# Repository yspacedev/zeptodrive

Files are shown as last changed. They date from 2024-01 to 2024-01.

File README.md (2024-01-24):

Constant current buck-boost converter based on the TPS63070 and INA180. The TPS63070 is a constant voltage buck-boost converter, so I'm using an INA180 (similar to this app note: https://www.ti.com/lit/an/slva419d/slva419d.pdf?ts=1689743420901) to convert it to a constant current converter.








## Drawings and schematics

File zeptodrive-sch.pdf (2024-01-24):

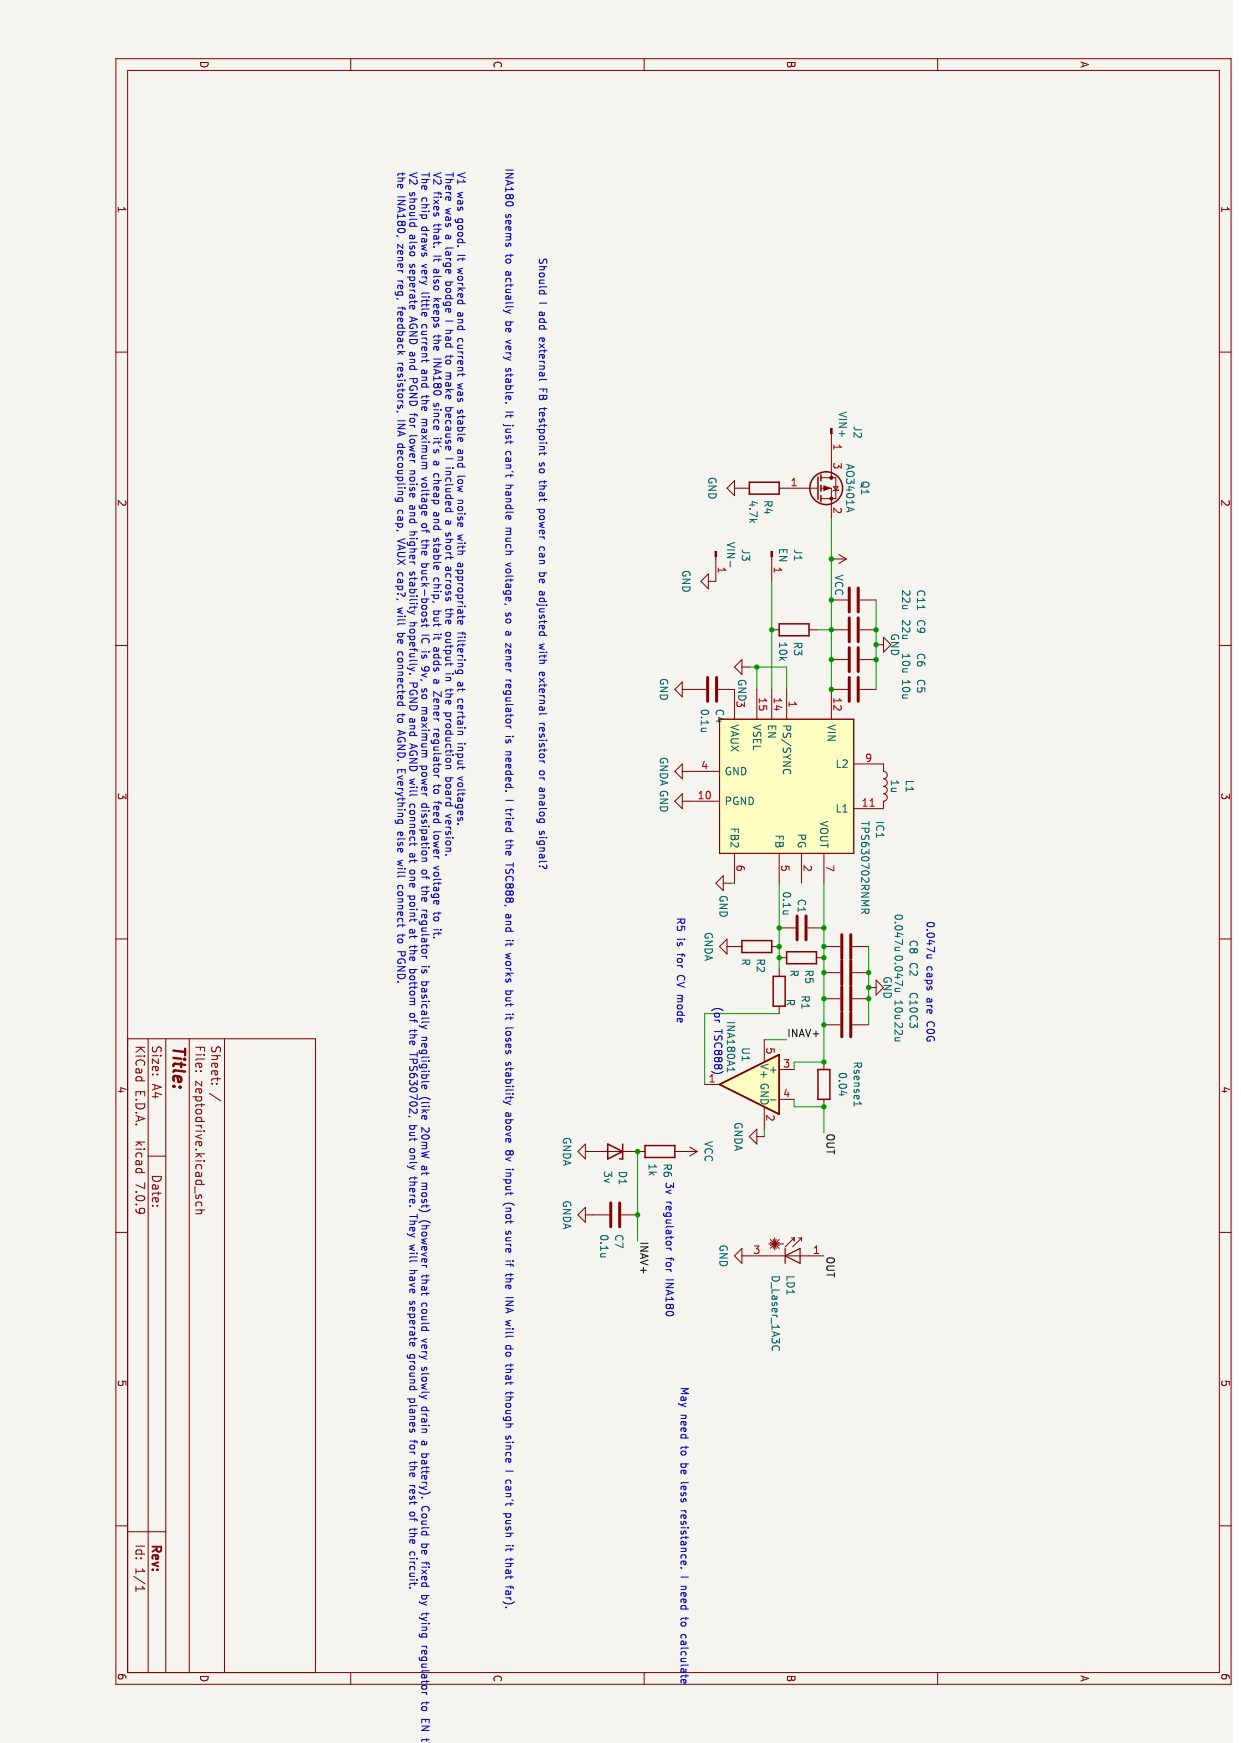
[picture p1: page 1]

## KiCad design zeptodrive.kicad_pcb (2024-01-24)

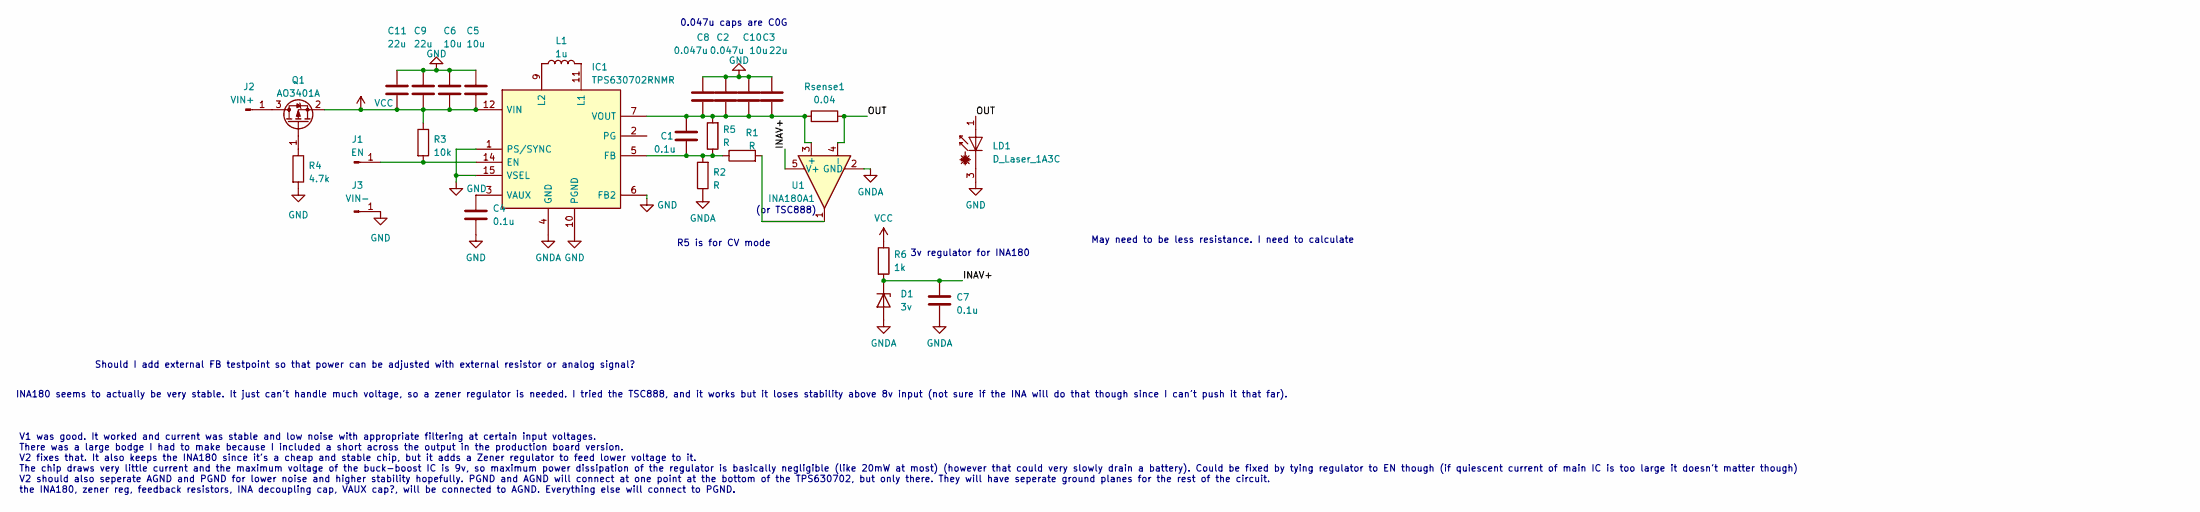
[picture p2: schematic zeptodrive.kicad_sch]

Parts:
C1, C4: 0.1u; C_0603_1608Metric
C2, C8: 0.047u; C_0805_2012Metric
C3, C9, C11: 22u; C_0805_2012Metric
C5, C6, C10: 10u; C_0805_2012Metric
C7: 0.1u; C_0402_1005Metric
D1: 3v; D_SOD-523
IC1: TPS630702RNMR; TPS630701RNMR; Mouser Part Number 595-TPS630702RNMR
J1: EN; TestPoint_Pad_D1.5mm
J2: VIN+; Small circular hole connector
J3: VIN-; Small circular hole connector
L1: 1u; L_1008_2520Metric
LD1: D_Laser_1A3C; Laser Diode Side Mount 1 side 2 pin
Q1: AO3401A; SOT-23
R1, R5: R; R_0603_1608Metric
R2: R; R_0805_2012Metric
R3: 10k; R_0603_1608Metric
R4: 4.7k; R_0603_1608Metric
R6: 1k; R_0402_1005Metric
Rsense1: 0.04; R_1206_3216Metric
U1: INA180A1; SOT-23-5

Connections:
/INAV+: C7.1, D1.1 (K), R6.2, U1.5 (V+)
/OUT: LD1.1 (A), Rsense1.2, U1.4 (-)
GND: C2.1, C3.1, C4.2, C5.1, C6.1, C8.1, C9.1, C10.1, C11.1, IC1.1 (PS/SYNC), IC1.6 (FB2), IC1.10 (PGND), IC1.15 (VSEL), J3.1, LD1.3 (K), R4.2
GNDA: C7.2, D1.2 (A), IC1.4 (GND), R2.1, U1.2 (GND)
unnamed: IC1.14 (EN), J1.1, R3.2
unnamed: C1.2, IC1.5 (FB), R1.1, R2.2, R5.1
unnamed: IC1.11 (L1), L1.2
unnamed: IC1.9 (L2), L1.1
unnamed: C4.1, IC1.3 (VAUX)
unnamed: J2.1, Q1.3 (D)
unnamed: Q1.1 (G), R4.1
unnamed: R1.2, U1.1
unnamed: C1.1, C2.2, C3.2, C8.2, C10.2, IC1.7 (VOUT), IC1.8 (VOUT), R5.2, Rsense1.1, U1.3 (+)
VCC: C5.2, C6.2, C9.2, C11.2, IC1.12 (VIN), IC1.13 (VIN), Q1.2 (S), R3.1, R6.1

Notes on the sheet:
V1 was good. It worked and current was stable and low noise with appropriate filtering at certain input voltages. There was a large bodge I had to make because I included a short across the output in the production board version. V2 fixes that. It also keeps the INA180 since it's a cheap and stable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
Should I add external FB testpoint so that power can be adjusted with external resistor or analog signal?
3v regulator for INA180
INA180 seems to actually be very stable. It just can't handle much voltage, so a zener regulator is needed. I tried the TSC888, and it works but it loses stability above 8v input (not sure if the INA will do that though since I can't push it that far).
(or TSC888)
May need to be less resistance. I need to calculate
R5 is for CV mode
0.047u caps are C0G

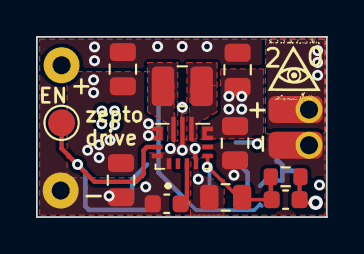
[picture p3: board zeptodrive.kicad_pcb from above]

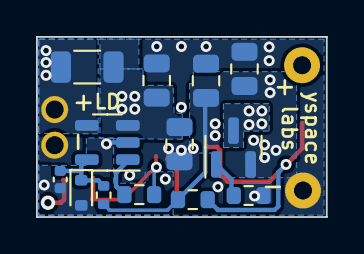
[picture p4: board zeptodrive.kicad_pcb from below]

Board: 4 copper layers, 16.1 x 10.0 mm, 27 parts (13 on the bottom side), 14 nets.
